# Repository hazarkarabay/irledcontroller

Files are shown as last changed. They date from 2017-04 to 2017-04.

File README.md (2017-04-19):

# irledcontroller
Simple LED Strip controller with IR remote control.

This project controls brightness of single LED strip from an IR remote. Currently it is using RC6 protocol because I have a MCE remote nearby. Thanks to [IRLib2](https://github.com/cyborg5/IRLib2), it can be configured to work with nearly any IR remote. 

Hardware
--------

A single-sided, toner transfer friendly PCB created for this project. Schematic and board files included in Hardware folder. You'll need [EAGLE](http://www.autodesk.com/products/eagle/free-download) for opening them.  
ATMega328 receives and decodes IR signals, reads an LDR to decide its status while first power-on and PWMs a N-Channel MOSFET to control lights. You'll need supply required voltage for your LED strip to this board. LED strips are generally 12V and board will work with 9-25V LED strips. 30V is absolute maximum for on-board regulator. On-board power MOSFET AO3406 can support up to 3.5A load, please check your strips' power requirement.  
Board also can support Arduino environment (supports DTS reset).

Software
--------

Software written in Arduino environment and commented heavily. Currently it uses 3 IR remote buttons to toggle light and increase/decrease brightness. It uses psychometric lightness formula (CIE 1931) for adjusting brightness and can fade in/out very smoothly (to human eye).  
Currently it uses Timer1 at 12bit mode for PWM. ATmega328 can switch at ~4kHz on this mode. Faster PWM frequencies needs reduced duty cycle resolution. 

Things to know
--------------

Since switching frequency of 4kHz is in audible range, this can leads audible noise. I did not hear anything in my application but you must aware of that.  
The board has an LDR and it only used in first power up. If the ambient light is low while powering on, it will fade lights to %100. After first start-up LDR status is ignored currently (no auto lights-on at night, sorry).  
ATMega328 is way overkill for this kind of project but I don't have any ATTinys in my hand. Because I have relatively high computing power at my hand, I didn't used lookup tables for CIE 1931 calculation, which deals with floats and exponentials. You probably want use a lookup table if you need to use ATTiny.  
If you want use serial debug output, uncomment `#define DEBUG` at line 21.
  


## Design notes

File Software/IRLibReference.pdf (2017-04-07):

User's Manual for IRLib2.

# A Library for Receiving, Decoding and Sending

Infrared Signals Using Arduino.

(September 2016)
This library is designed for using Arduino controllers for receiving, decoding and sending infrared signals such as those used by infrared remotes on consumer electronics. The work is based on an earlier library called IRremote which was created by Ken Shirriff. IRLib version 1.x was a major rewrite of that system. IRLib2 is a significant rewrite from IRLib 1.x. IRLib2 it is not fully backwards compatible with IRLib1 however it should take minimal effort to update any programs to use the new library. This is especially true if you are only using the interface of the library and not relying on any internals. See Appendix A for a discussion of the differences between IRLib2 and IRLib1 and an explanation of the reason for the choices I made in the rewrite. In this document any mention of IRLib should be construed to mean the current IRLib2 unless otherwise specifically specified. Also throughout the document we will make note of a few of the specific differences between IRLib2 and IRLib1.
One of the main differences we will note here is that IRLib1 was a single library with a single header file that included everything. You would make use of it by inserting the line… #include <IRLib.h>
However IRLib2 is more modular in design. It is actually organized into 6 different folders and many multiples of header files. To make the most efficient use of the libraries you should include only those header files which you actually need. However to assist in quickly converting older sketches to the new system, you can do…
#include <IRLibAll.h>

This will include the entire package into your sketch including all receivers and all protocols. While the linking loader will eliminate some portions of the library that you do not actually use, it will not eliminate everything that is unused. Additionally there is another file… #include <IRLib2.h>
This will include only the original seven protocols supported by IRLib1. The use of these all-inclusive include files is not recommended if you are concerned about the size of your code. We will use it occasionally in sample sketches just to simplify things. We will later describe the procedure for including only the specific pieces of the code that you actually need to use.
This manual is divided into three major sections. First is a complete reference of all the classes, structures and methods included in the library. The reference section is designed for those who want to make maximum use of the facilities of the library. However you may not need to understand everything in this section in order to use it. We suggest that novices proceed to part two which is the tutorials section. There you will find some examples of the basic use of the library. Finally you can move on to the third section of this documentation which explains how to add additional protocols to the decoding and sending sections.
There are also three appendices to this document. Appendix A as mentioned we explains the differences between IRLib2 and IRLib1 and gives an explanation of why we made the changes. Appendix B describes a special notation called IRP notation that is used in some online documentation to describe a particular IR protocol. Appendix C provide some guidance about our coding standards so that if you contribute to the library you can help maintain the same look and feel.
Note also that the code is well commented and skilled programmers who are familiar with infrared protocols and Arduino hardware or anyone interested should simply browse through the code itself for useful information.
This document is current for the original release of IRLib2 and may not be fully updated if there are minor bug fix releases. Always see CHANGELOG.txt for the latest information. The entire package of code, sample programs, and this documentation is copyright ©2016 by Chris Young and released under the GNU GENERAL PUBLIC LICENSE Version 3. See LICENSE.txt for a copy of the license. Also see COPYRIGHT.txt for more information including acknowledgment of major contributors to this package.

## 1. IRLib Reference

This section is intended to be a complete reference to the classes, methods, and structures used in the library. It is divided into the following sections:
1.1 Receiver Classes
1.2 Decoder Classes
1.3 Sending Classes
1.4 Protocol Details
1.5 Hardware Considerations

1.1 Receiver Classes
IR data is received on an input pin of the Arduino as a square wave of pulses of varying lengths. The length of the on and off pulses encodes the data. It is the job of the receiver class to record the timing of the pulses and the spaces between them. The data is stored in an array and passed to the decoder class. This section contains an overview discussion of the receiving process, with an explanation of the base receiver class and three derived classes each with its own unique characteristics. In addition to the receiver classes which records basic pulse widths, there is an additional receiver class for measuring the modulation frequency of an IR signal. 1.1.1 Receiver Overview
Infrared signals are received by an IR receiver device such as the TSOP4438 or TSOP58438 or similar. See the section 1.5 Hardware Considerations for details. Although IR signals are sent as a series of modulated pulses, these receivers filter out the modulations and send you a signal in the form of a clean square wave. If you want to measure the frequency of a modulated signal, you will need a device such as a TSMP58000 which does not filter the signal.

The output of the receiver is connected to one of the digital input pins of your Arduino. It is the job of the receiver class to monitor this signal and to determine the length of the pulses known as “marks” and the length of the intervening idle periods known as “spaces”. The hardware receiver devices typically are normally high signal and then go low when a signal is received. However the code compensates for this so it is useful to think of a “mark” as being “on” and a “space” as being “off”.

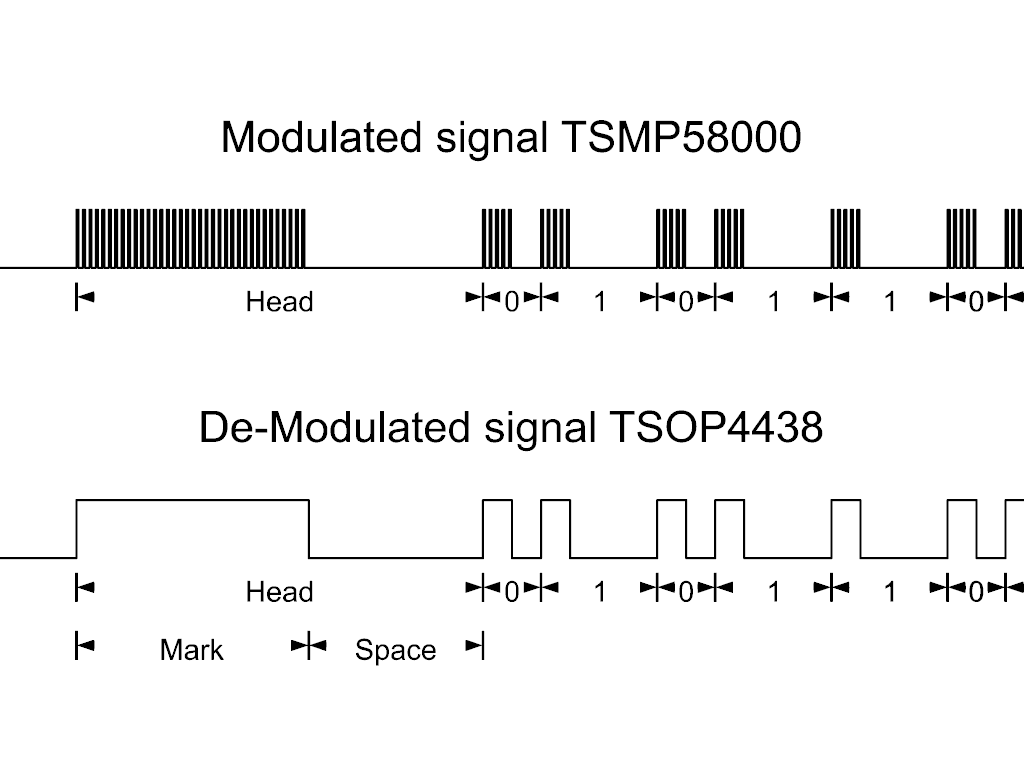
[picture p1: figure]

The duration of marks and spaces is measured in microseconds (1/1,000,000 of a second). Microseconds are often abbreviated as "µs". Note however that the software makes use of the built-in Arduino function “micros(void)” which returns results in four microsecond granularity. This means that values are always a multiple of four. This is for typical 16 MHz clocks on most Arduino models. On 8 MHz models results are in eight microsecond granularity. So whatever results we achieve are going to be no more accurate than that.
The receiver software is organized as a base class which of itself is not functional but contains methods which are common to all of the classes and three derived classes. Additionally there is a frequency measuring class is a library of its own. The classes are:
- IRrecvBase Abstract base class
- IRrecv | Original receiver class which uses 50 µs interrupt sampling
- IRrecvPCI | Uses pin change interrupts to measure pulse duration
- IRrecvLoop Uses a tight code loop to poll the input pin

- IRLibFreq Measures the modulation frequency using TSMP58000
The code for the base class and the IRrecvLoop can be found in the IRLib2 folder and the code for the other two derived receiver classes and frequency class each have their own folder. To use one of the receivers, you will have to include its header file in your sketch. You do not need to include the base class header file. You pass the pin number to which you receiver device is connected in the constructor of the object. For example to use the IRrecv receiver you would do the following…
#include <IRLibRecv.h>

IRrecv myReceiver(2);//create instance of receiver using pin 2
Similarly for the PCI version you would do…
#include <IRLibRecvPCI.h>

IRrecvPCI myReceiver(2);//create instance of receiver using pin 2 And finally the "loop" version would be…
#include <IRLibRecvLoop.h>

IRrecvLoop myReceiver(2);//create instance of receiver using pin 2
You can name the receiver object anything you want but to simplify our explanations we will presume that you have created a receiver object named "myReceiver". Although the library implements three different extensions to the base receiver class, you should have one and only one instance of a receiver class in your program. This is because all of the classes share one set of global data and methods in common. The data must be declared globally in the library because it is accessed by interrupt service routines (called ISR routines). The structure of an interrupt service routine does not allow for the passing of any parameters. Therefore any data that the ISR accesses must be global. It is possible to create both a receiver object and the frequency detection object but you should have no more than one of each.
The data is stored in an array of uint16_t values. The first element of the array is the number of microseconds from the time the receiver is enabled until the time the first mark is received. This gap is typically discarded by the decoding routines. From there on, odd-numbered elements of the array contain the duration of the marks and even-numbered elements contain the duration of the spaces.
Most of the receiver classes are interrupt driven. This means that once they are initialized, you can go off and do whatever you want until a complete sequence has been received. You determine when the sequence is complete by polling the method getResults() and when it returns true you can then obtain the results. Once a complete sequence has been received, the receiver class ignores any subsequent signals until it is reinitialized by you. However the IRrecvLoop is not interrupt driven. It does nothing until you call getResults(). It then sits in a tight loop and does not release control back to you until the complete signal has been received.
You should read the next section about the base class because most of the methods work identically regardless of which derived class you actually instantiate. You should then read the section on the class which you are going to use so that you will understand the class specific issues.

Here is an extremely simple sample sketch showing the use of the IRrecv class. Either of the other two classes could be substituted in this example. You may wish to refer to this sample code while reading the description of the methods.
#include <IRLibRecv.h>

IRrecv MyReceiver(2); //Create the receiver. Use pin 2

#include <IRLibDecodeBase.h>

#include <IRLib_P01_NEC.h>

#include <IRLibCombo.h>

IRdecode MyDecoder;

void setup() {
Serial.begin(9600);
MyReceiver.enableIRIn();//start receiving
}

void loop() {
if (MyReceiver.getResults()) {//wait till it returns true MyDecoder.decode();
MyDecoder.dumpResultso();
MyReceiver.enableIRIn(); //restart the receiver
}
}
1.1.2. The IRrecvBase class
This base class is an abstract class which in and of itself is not functional but contains common code for the other receiver classes. The code is implemented in IRLib2/IRLibRecvBase.cpp, and the prototype in IRLib2/IRLibRecvBase.h is…
class IRrecvBase {
public:
IRrecvBase(void) {};
IRrecvBase(uint8_t recvPin);
bool getResults()(const uint16_t timePerTicks=1); virtual void enableIRIn(void);
virtual void disableIRIn(void);
void enableAutoResume(uint16_t *P);
void setFrameTimeout(uint16_t frameTimeout); void blink13(bool enableBlinkLED);
uint16_t markExcess;
protected:
void init(void);
};

### 1.1.2.1 Constructor IRrecvBase

The prototype for the constructor is… IRrecvBase(uint8_t recvPin);

The value passed is the pin number to which the receiver is connected. Note: previous versions of the constructor for IRrecvPCI were passed the interrupt number instead of the pin number but now all receiver classes consistently have the pin number as its only parameter. Creating an instance of the receiver class does not enable the receiving of data. You must enable the receiver by calling enableIRIn().

### 1.1.2.2 Method enableIRIn

The receiver does not begin recording data until you call this method. Its prototype is… void enableIRIn(void);
This method sets the input pin to input mode and resets the index into the array of data values to zero. On the interrupt driven classes this enables interrupts and the receiver starts recording intervals. However when using the IRrecvLoop class, recording of signals does not begin until you call getResults().
Once the receiver is running you then need to poll the class to see if a complete sequence has been received. You do this by repeatedly calling getResults().
After you have finished processing the received data, you need to call enableIRIn() again to tell the receiver that you want more data. Even if you have enabled the auto-resume feature, you still need to call this method when you are ready for more data so that the receiver knows that it is safe to reuse the buffer. We considered renaming this method to "needMoreData" but in the long run its current name is more accurate. A complete discussion of the auto resume feature can be found in the section 1.1.2.4 Method useAutoResume below. NOTE: In IRLib1 there were 2 methods for starting the receiver. The method "myReceiver.enableIRIn()" was used to initialize the receiver and the method "myReceiver.resume()" was used to restart the receiver after you had finished processing the data. However if you also use the sending class it would disable input because it uses the hardware timers for different purposes. Therefore you would have to use "enableIRIn()" to restart after sending. It got too confusing to remember whether you needed to use "resume()" or "enableIRIn()" so we just eliminated the "resume()" completely. That method no longer exists in IRLib2. Now you just use "enableIRIn()" whether you are initializing for the first time or restarting. See Appendix A for more details.

### 1.1.2.3 Method getResults

After you have initialized receiving with enableIRIn you need to repeatedly call getResults() to see if a complete sequence has been received. The prototype for this method is…
bool getResults(const uint16_t timePerTicks=1);
This method will return “true” when a complete sequence has been received and will return “false” otherwise. The optional parameter is a multiplier which converts the recorded data into microseconds. The IRrecv class produces results in 50 µs ticks. It passes the number 50 as the parameter so that getResults() will multiply the values in the array by 50 to convert them into actual microseconds. The other two receiver classes use the default multiplier 1 because they record actual microseconds and do not need converting. This parameter is only used by the base class and is not necessary or present in any of the actual derived classes you will use. When a complete sequence has been received by the class it does not continue recording signals. It also does not normally resume recording once you have called getResults() because your decoder may be using the same array as the receiver and you do not want the receiver overwriting the array before you get it decoded.
To resume receiving data you must again call "enableIRIn()".

### 1.1.2.4 Method enableAutoResume

All three receiver classes capture their data in a globally declared buffer we will describe as the "receiver buffer". The decoders access that data through a pointer which points to what we will describe as the "decoder buffer". Normally the decoder buffer pointer points to the receiver buffer so they essentially same buffer.
If the receiver would continue recording the next frame of data before you had finished processing the first one, it would get overwritten. In some instances however you want it to resume receiving as quickly as possible so you do not miss the next frame while you are processing the first one. You can however declare an external buffer for the decoder to use and tell the receiver that it should automatically copy the data from the receiver buffer to your external decoder buffer and automatically resume. This is especially useful to use this external buffer and auto resume whenever you are using the IRrecvPCI receiver. That receiver has difficulty determining that the first frame has completed unless a secondary frame has begun. We highly recommend the use of this auto resume feature whenever you are using the IRrecvPCI receiver. Of course this feature requires 200 bytes of RAM memory which is very scarce on most Arduino platforms so you may not be able to use this feature if you cannot afford to declare the extra buffer space.
Note that this method is not available when using the IRrecvLoop receiver class because that class is not interrupt driven. Therefore you cannot multitask by receiving signals while you are decoding a previous sequence.
The prototype for this method is…
void enableAutoResume useExtnBuf(uint16_t *P);
Below is an excerpt of the autoResume sample sketch that shows how to use this method. You declare the buffer and then invoke the method in your setup function prior to starting the receiver with enableIRIn(). When a sequence is complete and getResults() returns true, the data will be copied to "myBuffer" and it will automatically start recording the next available sequence even though you have not yet invoked enableIRIn().
Whether using auto resume or not, in your main loop do not re-invoke enableIRIn() until after you have processed all of the data. If by chance you have not finished processing the first frame when the second one is completed, the receiver will not auto resume again until you have invoked enableIRIn(). Essentially invoking that method tells it that it is safe to write into the decoder buffer.
uint16_t myBuffer[RECV_BUF_LENGTH];

void setup() {
//Enable auto resume and pass it the address of your extra buffer myReceiver.enableAutoResume(myBuffer);
myReceiver.enableIRIn(); // Start the receiver
//… Other initialization code here…
}
void loop() {
//Continue looping until you get a complete signal received if (myReceiver.getResults()) {
myDecoder.decode(); | //Decode it
myDecoder.dumpResults(true); //Now print results myReceiver.enableIRIn(); //Tell receiver we are ready
}
}
You should only invoke enableAutoResume one time in your setup function and it must be before enableIRIn().
NOTE: In IRLib1 there was a decoder method "useExtnBuf(void *P)" that
would allow you to manually resume receiving before you were done
processing the data. It did not however solve the problem with IRrecvPCI possibly missing the secondary frame. When we first implemented auto resume, we implemented was an option in the useExtnBuf method however was extremely confusing when you should call enableIRIn. If you are using external buffer but using auto resume then you would reenable before decoding. But if you are using auto resume you would reenable after decoding. We eventually concluded that auto resume was so useful that there was no reason to use an external buffer without it. It also made more logical sense to make this a method of the receiver class than the decoder class. It isn't so much about adding an external buffer to the
decoder but it is more about changing the behavior of the receiver. See
Appendix A for more details.
Many thanks and acknowledgment to contributor Gabriel Staples who contributed auto resume code that was inspiration for our implementation.

### 1.1.2.5 Method setFrameTimeout

The receiver measures the length of marks and spaces and when it finds an especially long-duration space it assumes that is the end of the frame of data. This time period is called the "frame timeout" value. Any space which is found to exceed that value is presumed to be the end of frame and a new frame begins with the next mark. The default value is specified in IRLib2/IRLibRecvBase.h as follows…
#define DEFAULT_FRAME_TIMEOUT 7800

If you wish to change the value for a particular application sketch you can do so with the following method…
void setFrameTimeout(uint16_t frameTimeout);
We chose the default value to be 1.25 times the largest space any valid IR protocol might have. Our research shows that in Ken Sherriff's IRremote library ir_Dish.cpp they use

DISH_RPT_SPACE 6200 while another reference says about 6000. If we take 6200*1.25= 7750 rounded up we will use 7800. Previously IRLib1.x the default value was 10000 which was probably too large. Thanks to Gabriel Staples for this note. We had to implement this is a method because the IRrecv class needs to convert this value into a number of ticks.

### 1.1.2.6 Method blink13

For debugging purposes you may want to know if your Arduino is receiving a signal. If you call this method then pin 13 will be blinked on every time a mark is received and blinked off with a spaces received. The default is off. The prototype is…
void blink13(bool enableBlinkLED);

### 1.1.2.7 Method disableIRIn

Even when not receiving data or waiting to receive data, the ISR may remain active but remains in a do-nothing state. If you want to truly shut down the ISR you can call this method. The derived method should disable the ISR and then call this base method to then turn everything off. The prototype is…
void disableIRIn(void);

### 1.1.2.8 Variable markExcess

There is one value in the class that you can change directly. It is…
uint8_t markExcess;
Depending on the type of IR receiver hardware you are using, the length of a mark pulse is over reported and the length of a space is underreported. Based on tests performed by Ken Shirriff who wrote the original IRremote library upon which this library is based, the length of a received mark is about 100µs too long and a space is 100µs too short. IRLib1.x used that value however my own experience is that 50µs is a better value so that is the default for IRLib2. You can change that value based on your own experiences by changing the value for example… myReceiver.markExcess= 75;
You can examine or change this variable as desired. It is applied by adding that value to all odd-numbered elements of the time interval buffer and is subtracted from even-numbered elements when the data is passed to your decoder by getResults().

### 1.1.2.9 Protected Method init()

There is one protected method of the base class which is used for internal use.
void init(void);
Because it is protected you cannot call it in your sketch and you would have no need to do so.
1.1.3. IRrecv Class
This receiver class is based on the original receiver created by Ken Shirriff in his library IRremote upon which this library is based. It uses a hardware timer to trigger an interrupt every 50µs. Inside the interrupt routine it counts the number of these 50µs ticks while the pin is a mark and when the state changes it counts how many ticks in the space. When it receives an extraordinarily long space it presumes that the sequence has ended. It sets an internal flag noting that the sequence has been received. It stops recording time intervals and when the user calls getResults() the next time it will return true.
The internal hardware timer used is controlled by settings in the file IRLibProtocols/IRLibHardware.h. Each type of Arduino platform such as Arduino Uno, Leonardo, Mega etc. has a choice of different timers. For example the Uno defaults to TIMER2 while the Leonardo defaults to TIMER1 because it does not have a TIMER1. You may need to change the default timer in the event of a conflict with some other library. For example the Servo library makes use of TIMER1 so if you’re using a Leonardo with a servo you would need to change the value in IRLibHardware.h to use a different timer.
The prototype of the class is in IRLibRecv/IRLibRecv.h and the code is implemented in IRLibRecv/IRLibRecv.cpp. This makes this class essentially a library of its own. If it had been included in the IRLib2 folder, it's globally declared ISR might conflict with other libraries even if you did not create an instance of this class. The prototype is…
class IRrecv: public IRrecvBase {
public:
IRrecv(uint8_t recvPin):IRrecvBase(recvPin){}; void enableIRIn(void);
bool getResults(void);
void disableIRIn(void);
void setFrameTimeout(uint16_t frameTimeout);
};
Of course this class also inherits other methods from the base class that are not listed in this prototype. As previously noted in the discussion of the base class, the constructor is passed the pin number of the input pin to which you have connected your receiver. There are no restrictions and any digital input pin can be used.
You will need to enable input by calling enableIRIn() and will need to poll the getResults() method in your loop until it turns true. Although in our example code we called getResults() in a very small loop, because this class is interrupt driven you can do just about anything else inside your main loop function and only call getResults() when you are ready.
A reminder that when a complete stream has been received, no additional measurements are taken until you call the enableIRIn() method again. Do not call enableIRIn() until you are finished with the data from the previous frame even if you have enabled auto resume.
Because this receiver only samples the input every 50µs there is a chance that it could sample at inopportune times and be as much as 98µs off when measuring intervals. If you are decoding a known protocol, this margin of error is usually acceptable. The decoder functions typically use +/-25% tolerance and that produces acceptable results. However if you are trying to analyze an unknown protocol you would be better suited to use either the IRrecvPCI or IRrecvLoop receiver class instead.

1.1.4. IRrecvPCI Class
This receiver class makes use of the hardware interrupt available on some pins of Arduino microcontrollers. It was created because it gives more accurate timings than the original IRrecv class which only samples the input every 50µs. The code as well as the IRfrequency code described in the next section is loosely based upon and inspired by work by the developers of the AnalysIR program. AnalysIR is a Windows-based application which allows you to graphically analyze IR input signals through an Arduino, Raspberry Pi or other microcontrollers systems. Many thanks to the developers of that software for their assistance and input into the development of this class. You can find more about their software at http://analysir.com
The class sets up the pin change hardware interrupt which calls the interrupt service routine every time the input pin switches from low to high or high to low. At each change, the code calls the built in function micros() and that value is subtracted from the timestamp of the previous change. Because the micros() function is only accurate to 4µs on 16 MHz systems or 8µs on 8 MHz systems, that is the limitation of accuracy of this method.
While it is much more accurate than the original IRrecv class which only had 50µs or worse accuracy, it may not be suitable for everyday use. The class has difficulty determining when a sequence has ended. Normally we assume a sequence has ended when a space interval is longer than a certain amount. But we cannot know how long the final trailing space is until the first mark of the next sequence begins. The code attempts to compensate for this by checking for an extremely long space each time that the user calls getResults(). However unless you call that routine extremely frequently, it is more likely that the next sequence will begin. While that does not adversely affect the reception and subsequent decoding of an initial sequence, if the next sequence comes quickly then the receiver may miss it or may start reception in the middle of a sequence thus giving only partial and therefore jumbled results. This problem can be alleviated by using the auto resume feature however that requires an external buffer which can use up a considerable amount of valuable RAM memory. Auto resume will ensure that 2 frames that arrive close together will be properly received and decoded so it is highly recommended when using this type of receiver.
As with the IRrecv class, the interrupt service routine is put into an idle state once a completed sequence has been detected and is not re-enabled until you call enableIRIn().
The prototype of the class is in IRLibRecvPCI/IRLibRecvPCI.h and the code is implemented in IRLibRecvPCI/IRLibRecvPCI.cpp. This makes this class essentially a library of its own. If it had been included in the IRLib2 folder, it's globally declared ISR might conflict with other libraries even if you did not create an instance of this class. The prototype is…
class IRrecvPCI: public IRrecvBase {
public:
IRrecvPCI(uint8_t pin);
void enableIRIn(void);
bool getResults(void);
void disableIRIn(void);
private:
uint8_t intrNum;
};

Of course this class also inherits other methods from the base class that are not listed in this prototype. As previously noted in the discussion of the base class, the constructor is passed the pin number of the input pin to which you have connected your receiver.
NOTE: In IRLib1 the constructor for this class was passed the interrupt
number and not the pin number. This behavior has changed to be pin number. It then converts that pin number into the interrupt number using the built-in Arduino function "digitalPinToInterrupt(pin)" as is
recommended at https://www.arduino.cc/en/Reference/AttachInterrupt
See that page for more details.
Only certain particular pins support the pin change interrupt depending on which type of Arduino you are using. You can verify that the pin is supported by putting the following code in your setup function.
#define MY_PIN 2 //pin number 2 if(digitalPinToInterrupt(MY_PIN)==NOT_AN_INTERRUPT) { Serial.println(F("Invalid frequency pin number."));

while (1) {};//infinite loop because of fatal error
}
The table below is a partial list of the pin numbers that are available on various platforms. The table was adapted from http://arduino.cc/en/Reference/AttachInterrupt and you should reference that page for more information about the Arduino built in function attachInterrupt() that is used by this class.
Board | Digital Pins Usable For Interrupts
Uno, Nano, Mini, other 328-based | 2, 3
Mega, Mega2560, MegaADK | 2, 3, 18, 19, 20, 21
Micro, Leonardo, other 32u4-based | 0, 1, 2, 3, 7
Pinoccio | 4, 5, SCL(15), SDA(16), RX1(13), TX1(14), 7
Zero* | all digital pins, except 4
MKR1000 Rev.1* | 0, 1, 4, 5, 6, 7, 8, 9, A1, A2
Due* | all digital pins
101* | all digital pins
*These platforms have not been tested with IRLib but should theoretically work with this receiver. They are not however supported for sending IR signals or using the IRrecv receiver class.
You will need to enable input by calling enableIRIn() and will need to poll the getResults() method in your loop until it turns true. Although this receiver is interrupt driven and you should be able to do just about anything inside your main loop, we recommend that you call getResults() as frequently as possible because this receiver has difficulty detecting when a frame is complete. If however you are using the auto resume feature, this restriction is not necessary. You can take considerable time doing other things in your main loop when using auto resume. We recommend that if you can afford to allocate an external buffer and use auto resume that you should do so with this receiver for best results.
A reminder that when a complete stream has been received, no additional measurements are taken until you call the enableIRIn() method again. Do not call enableIRIn()

until you are finished with the data from the previous frame even if you have enabled auto resume.
1.1.5. IRrecvLoop Class
This version of the receiver class uses a tight internal loop to poll the input pin. It makes no use of hardware interrupts or internal timers to compute the intervals. It does use the “micros()” function to compute time intervals so it has the limitations of that function. Specifically the function is only accurate to 4µs on 16 MHz systems or 8µs on 8 MHz systems. Although we have attempted to code the loop as tightly as possible there still is some amount of overhead in the loop itself which could affect the accuracy. However it is still much more accurate than the 50µs off the original IRrecv. This makes it a good choice for analyzing unknown protocols. Because no interrupts are involved, the class does not begin recording intervals when you initially call enableIRIn() as is the case with other classes. This class only samples input when you call getResults(). That method then takes over control of your program and does not relinquish it until it has received a complete sequence. The function always returns true. Because it takes over control of your program and does not allow you to do other things while it is looking for a sequence, this version of the class may not be practical for everyday use. This class cannot make use of the auto resume feature because it is not interrupt driven and therefore cannot multitask.
You will still need to call enableIRIn() when you have finished processing your data to get the receiver ready to receive again. However the actual data collection will not begin again until you call getResults().
The prototype of the class is in IRLib2/IRLibRecvLoop.h and the code is implemented in IRLib2/IRLibRecvLoop.cpp. Unlike the IRLibRecv and IRLibRecvPCI, this receiver should never conflict with any other libraries. For that reason it does not need to be a library unto itself. The linking loader will eliminate it completely if you do not create an instance. Therefore the code files are located in the IRLib2 folder. The prototype is…
class IRrecvLoop: public IRrecvBase {
public:
IRrecvLoop(uint8_t recvPin):IRrecvBase(recvPin){};
bool getResults(void);
};
Although the prototype only lists the constructor and getResults(), all of the methods of the base class are technically available. However as we mentioned earlier, auto resume is not available so enableAutoResume() does nothing. Similarly because it is not interrupt driven the method disableIRIn() does nothing. Like the other receivers, the value passed to the constructor is the number of the receiver pin. Any available digital input pin can be used.
Because this class uses no hardware timers and no hardware interrupts it is completely hardware independent and should work on any Arduino-like platform even those which are not technically supported by this library.
1.1.6. Global Receiver Structures and Functions
There are 3 additional global functions in IRLib2/IRLibRecvBase.h and implemented in IRLib2/IRLibRecvBase.cpp. These functions are not methods of any class. Two of these are global because they are referenced internally by the ISR and you cannot pass variables or objects to an ISR. The third of these global functions is somewhat related to both sending and receiving but doesn't really belong in either class. In this section we will also describe a structure containing other global variables that were again made global so that they can be referenced inside the ISR.

### 1.1.6.1 Function IRLib_noOutput

Some users create custom boards for input and output of IR signals and those boards are connected to their Arduino even in the case when the sketch only does input. It is theoretically possible that when running an “input only” sketch that the output pin could initialize high and your output LED would be on all the time. LED driver circuits are sometimes designed to overdrive the LED because it is used only intermittently. If it were to be accidentally left on continuously, it could burn out your circuit. If you want to ensure that this does not happen you can call this function. We are unsure if this function is actually necessary but we provide it out of an abundance of caution. The prototype is…
void IRLib_noOutput(void);
NOTE: This previously was a method of the base receiver class but it really doesn't have anything to do with receiving so we renamed it and made it a standalone function.

### 1.1.6.2 Function IRLib_doBlink

This function is for internal use only. It is called by the ISR or in the case of the loop receiver by IRLibRecvLoop::getResults(). It does actual blinking of the pin 13 indicator LED. The prototype is…
void IRLib_doBlink(void);

### 1.1.6.3 IRLib_IRrecvComplete

This function is for internal use only. It is called by the ISR and implements much of the logic of the auto resume feature. It is not used by IRLibRecvLoop::getResults() because that receiver does not support auto resume. The prototype is…
void IRLib_IRrecvComplete(uint8_t Reason);
This function is called by both the 50us and PCI ISR in one of two circumstances:
1) The SPACE was long enough that we are sure the frame is over and ready to process.
2) The buffer overflowed we have to quit.
The parameter is for debugging purposes only.

### 1.1.6.4 Global data recvGlobal

In addition to the base class and the three derived classes that are used for receiving IR signals, there is a globally defined structure that is used by the classes. Good object-oriented design would have us put all of the data associated with a class inside the class itself. However much of the data we use needs to be accessible from an interrupt service routine. A limitation of an ISR is that we cannot pass it any parameters and it cannot be part of a class. So all of the data used by the ISR must be in some globally available location. Unless you’re going to implement your own receiver class or you create custom decoder classes need access to this data, you need not deal with the structure. It is primarily for internal use. The type "recvGlobal_t" defined in IRLib2/IRLibGlobal.h as shown below. A single global instance of the structure is declared in IRLib2/IRLibRecvBase.cpp as follows
recvGlobal_t recvGlobal;
Additionally the ISR routines keep track of what they're doing by implementing a state machine. The state machine is only used by the IRrecv and IRrecvPCI classes. The current state of the state machine is stored in a field of the global structure of type "currentState_t". Below is the definition of the states of the state machine, and the 2 structure types that are used by the receivers. The actual code in IRLib/IRLibglobal.h Is more extensively commented than what is shown here. We will briefly describe each field below.
// Receiver states. This previously was enum but changed
// it to uint8_t to guarantee it was a single atomic 8-bit value. #define STATE_UNKNOWN 0
#define STATE_READY_TO_BEGIN 1

#define STATE_TIMING_MARK 2

#define STATE_TIMING_SPACE 3 #define STATE_FINISHED 4

#define STATE_RUNNING 5

typedef uint8_t currentState_t;

typedef struct {
uint8_t recvPin; | // pin number for receiver
bool enableAutoResume; // flag tells if we should auto resume uint16_t frameTimeout; // set by "setFrameTimeout()" uint16_t frameTimeoutTicks;// = frameTimeout/USEC_PER_TICKS

bool enableBlinkLED;

volatile bool decoderWantsData; //previous decode is finished. volatile bool newDataAvailable; //tells getResults
volatile bool didAutoResume; //tells getResults

volatile uint16_t recvBuffer[RECV_BUF_LENGTH];
volatile bufIndex_t recvLength;

volatile uint16_t* decodeBuffer;
volatile bufIndex_t decodeLength;
volatile uint32_t timer; | // state timer, counts 50uS ticks
volatile currentState_t currentState; | // state machine
}
recvGlobal_t;
extern recvGlobal_t recvGlobal; //declared in IRLibRecvBase.cpp
The first four fields of the recvGlobal structure are initialized by the receiver class and once initialize will probably not change. The first three are pretty much self-explanatory. The field uint16_t frameTimeoutTicks is only used by the 50 µs IR recv class it is always equal to frameTimeout/USEC_PER_TICKS (which is almost always 50).
The next field enableBlinkLED tells whether or not to blink indicator LED.
The remaining fields are declared volatile because they may be accessed both inside and outside the ISR. The next three fields are flags that help facilitate auto resume. The flag decoderWantsData is the way the decoder tells the ISR that it is safe to write new data into the decode buffer. The flag newDataAvailable is the way the ISR tells getResults() that a complete sequence has been received. The flag didAutoResume is set by the ISR and tells IRLibRecvBase::getResults() that because we did auto resume, the ISR has already copied the data from recvGlobal.recvBuffer to recvGlobal.decodeBuffer. However getResults() still needs to perform some math on the data to convert from ticks to microseconds if necessary and to make the "markExcess" adjustments.
The field recvBuffer[RECV_BUF_LENGTH] is the actual receive buffer. The receivers always initially accumulate the timing of the marks and spaces in this buffer. The field recvLength tells the number of entries in that buffer.
The field decodeBuffer is a pointer that the decoders use to access the timing data. If there is no external buffer for auto resume then this pointer will point to recvGlobal.recvBuffer and essentially the decode buffer is the receiving buffer. However if an external buffer and auto resume have been enabled, then this pointer points to that external buffer. In that case the external buffer is the decode buffer. The field decodeLength is the number of entries in the decode buffer.
The field uint32_t timer is a temporary variable used to count the number of ticks or microseconds of the current interval.
The field currentState_t currentState is the current state of the state machine. Its legal values are defined above.
Near the top of IRLib2/IRLibGlobal.h are the following definitions…
#define RECV_BUF_LENGTH 100

#if (RECV_BUF_LENGTH > 255)

typedef uint16_t bufIndex_t;
#else

typedef uint8_t bufIndex_t;
#endif

The #define is the length of the receiver and decoder buffers. The default value of 100 will work for most electronic protocols. However some protocols used by air conditioners and fans have extremely lengthy frame sizes. Because each entry in the buffer is uint16_t it will use two bytes of RAM. You'll want to use as small value as possible. If you need more than 255 entries, the conditional compile directives will make sure that your index into the buffers is sufficient to handle that many entries.
1.1.7 IRfrequency Class
Normally you would use a TSOPxxxx IR receiver device to detect IR signals. These devices demodulate the signal into square waves measured in hundreds or thousands of microseconds. However the actual IR signals are modulated at frequencies from 36 kHz as high as 57 kHz depending on the protocol. If you have an unknown protocol, you can typically receive such a signal using a device that has been tuned to 38 kHz however if you then want to accurately retransmit the signal you need to know the actual frequency. This requires a different type of receiver such as a TSMP58000 that passes the modulated signal through directly. See the section Hardware Considerations for more info on connecting these devices.
Because the signals are so short (17.5 µs to 27.7 µs) it is difficult to accurately measure them. The only way is to use a hardware interrupt pin and an extremely fast interrupt service routine. However these measurements are limited to the accuracy of the micros() function which is only accurate to 4 µs on 16 MHz systems and 8 µs µs on 8 MHz systems. The accuracy of the measurement can be slightly improved by taking several hundred measurements and averaging them.
The IRfrequency class implements an interrupt driven system for measuring frequency. See the examples folder for sample code using this class. The IRLibFreq/dumpFreq example requires both a TSOP and TSMP device connected to 2 different pins. It detects both the frequency using IRfrequency and the pattern of pulses using IRrecvPCI or IRecvLoop receivers. You could also use the original IRrecv receiver class but it degrades the accuracy of the frequency calculation because the interrupt every 50 µs interferes. The other sample code is IRLibFreq/freq and it uses only the TSMP device to measure frequency and it does nothing else. Measuring frequency by itself is the most accurate method but there may be applications where you need to measure frequency and protocol simultaneously.
The class is not derived from the IRLibRecv class. It is a library unto itself with the code implemented in IRLibFreq/IRLibFreq.cpp. The prototype in IRLibFreq/IRLibFreq.h is…
class IRfrequency {
public:
IRfrequency(uint8_t pin);
void enableFreqDetect(void);
bool haveData(void); //detect if data is received void disableFreqDetect(void);
void computeFreq(void); //computes but does not print results
void dumpResults(bool detail); //computes and prints result double results; //results in kHz
uint8_t samples; //number of samples used in computation private:
volatile FREQUENCY_BUFFER_TYPE Time_Stamp[256];
uint8_t intrNum;
uint16_t i;
uint32_t sum;
};

### 1.1.7.1 Constructor IRfrequency(uint8_t pin)

The parameter to the constructor is the pin number to which you will connect your TSMP58000 device. Note previous versions of this library you would pass the interrupt number rather than the pin number. Only particular pins which can use the pin change interrupt can be used. See section on the IRrecvPCI class for a table showing which pin numbers are available on a particular platform. There is also sample code that shows how to see if you have chosen a valid pin number.
As with other receiver classes, you should instantiate only one copy of this class. However you can simultaneously have a frequency receiver and one of the other normal receivers at the same time.

### 1.1.7.2 Method enableFreqDetect

The class does not begin collecting frequency data until you call the enableFreqDetect() method. This attaches the interrupt routine and begins waiting for a signal. The built in interrupt service routine calls micros() each time a signal is detected. It stores the least significant 16 bits of that value in a 256 byte array. It continually detects data in the array and when it fills, the index wraps around. This overflow is very likely to occur because an IR stream will usually contain thousands of pulses. Therefore the measurement is only based upon the most recent 256 data points.
The system uses only 16 bits of timing data which is generally sufficient. If you can use more or less RAM memory, you can change the value…
#define FREQUENCY_BUFFER_TYPE uint16_t

This value can be found in IRLibFreq/IRLibFreq.h and can be changed to either uint8_t or uint32_t however 16 bit default is generally best.
If you are simultaneously receiving a signal using a TSOPxxxx device and one of the three available receiver classes as in the dumpFreq example, you can continue to operate the frequency detector until a complete sequence has been detected. However if you are measuring frequency alone as with the freq example, you need to know when to quit. You can call the haveData() method repeatedly in your main loop. It will return true if at least one buffer full of data has been collected.

### 1.1.7.3 Method disableFreqDetect

When you are finished collecting data, you should call the disableFreqDetect() method. This will detach the interrupt and no further data is collected until you call enableFreqDetect() to again. In the normal receiver classes it generally does not hurt anything to leave interrupts running however this class you really should disable it once you have collected sufficient samples. Otherwise the receiver continues collect data overwriting the data collected.

### 1.1.7.4 Methods computeFreq and dumpResults

Once you have collected the data, you then have a choice of either calling computeFreq which computes the frequency based on the timestamp data or dumpResults which will call computeFreq for you and display the results using Serial.print().
The computation measures the difference between successive timestamps. While the majority of the timestamps will be the time between pulses of the modulated signal, some of them will be the gaps caused by the spaces in the protocol. These gaps will be on the order of hundreds of microseconds rather than tens of microseconds. The computation discards these intervals and only considers those which are likely to be from the modulated signal itself. Because we’re only storing the least significant 8 to 16 bits of data, some of the values will be inaccurate. The code attempts to eliminate anything that is unusually large or unusually small. It then averages the usable samples and computes a frequency measured in kHz. The computeFreq method stores the results in a float double variable myReceiver.results. It also tells you the number of actual samples used in the computation in the myReceiver.samples. If the samples value is extremely small, you might wish to discard that data and remeasure.
1.2 Decoder Classes
IR signals are encoded as a stream of on and off pulses of varying lengths. The receiver classes only record the length of pulses which we call “marks” and the intervals between them which we call “spaces”. However it is the decoder class which identifies the protocol used and extracts the data. It provides the user with the type of protocol it found if any, the value received, and the number of bits in that value. We implement the decoder as an abstract base class and a number of additional derived classes with one class for each protocol supported. Additionally there is a class will turn your received data into a 32-bit hash code which can be used for creating a unique data value from an unknown protocol. Note however that the hash code is only good for detecting signals and cannot be used to re-create the signals for sending again. NOTE: In IRLib1 there was a universal class which incorporated seven of the supported protocols. Additional protocols were supported only through sample sketches which illustrated how to extend the base class to incorporate more protocols. If you wanted to use only one or two protocols or wanted to incorporate any protocols beyond the original seven, it required a great deal of programming on the part of the developer to use this library. The new modular design used by IRLib2 has you include the base decoding class, followed by header files for only the protocols you wish to use, followed by a file which will assemble into a decoder using all and only the protocols you want. That process is described in section
1.2.3 The Combo Decoder Class.
1.2.1. Decoding Overview
The data from the receiver class is in the form of an array of time intervals of the marks and spaces that constitute the data stream. That stream typically begins with some sort of header followed by the encoded bits of data which could be from 8 up to 32 or more bits followed by some trailer. Occasionally there are other sequences in the middle of the stream that are not actually part of the data. These signals serve to separate the data into different sections. In order to make good use of the information we need a decoder which will take this data and converts it into a single binary value which identifies the particular function the remote is using.
The data sent by a remote often contains information such as a device number, sub-device, function number, sub-function and occasionally information that designates that this is a repeated signal. The philosophy of this library is to not care about what the data represents. We take the philosophy that “You push the button and this is the stream of data that you get.” Our job is to get you that binary number usually expressed in hexadecimal and it’s up to you to decide what to do with it.
If you are using a supported protocol, that hexadecimal number can then be fed into a send class which will output the IR signal identical to the one that you received. There is one exception in that one of the decoders used for unknown protocols creates a 32-bit hash code from the input sequence. The hash code is extremely likely to be a unique representation of the original stream but there is no way to reverse that and re-create the stream from the hash code.

Different manufacturers use different protocols for encoding this data. That is what allows you to have a universal remote that can operate devices by different manufacturers and not have the signals get mixed up. That creates a problem for us because we need different programs to decode each different protocol. The library has a base decoder class each protocol has a derived class based on base class. There is also a special hash decoder class and another base class which defines common methods used by both RC5 and RC6 protocols. Below is a version of our example sketch IRLib2/examples/dump/ which you can use as a guide throughout this discussion. Note that this example uses IRLibAll.h to simplify the example but it is not recommended because it includes more code than is necessary and can make your application larger than needed. We recommend you use the combo system which we will describe in section 1.2.3 The Combo Decoder Class.
#include "IRLibAll.h"

IRrecv myReceiver(2); //create receiver and pass pin number
IRdecode myDecoder; //create decoder

void setup() {
Serial.begin(9600);
delay(2000); while (!Serial); //delay for Leonardo myReceiver.enableIRIn(); // Start the receiver Serial.println(F("Ready to receive IR signals"));
}

void loop() {
//Continue looping until you get a complete signal received if (myReceiver.getResults()) {
myDecoder.decode(); | //Decode it
myDecoder.dumpResults(false); //the results of a Now print results.
myReceiver.enableIRIn(); //Restart receiver
}
}
The IRLibAll.h among other things defines a new derived class called IRdecode which combines all of the supported protocols into a single class. You should then create an instance of that class. That file also makes available all three receiver classes so we will create a receiver as well for this example.
In the setup function it initializes the serial monitor, initializes the receiver, and prints a prompt message to the serial monitor. In the main loop we continually call myReceiver.getResults() and when it returns true we call myDecoder.decode(). That method will return "true" if it discovered one of the protocols that you are using. In this instance we want to see the results even if it did not correctly decode the data so we are ignoring the return value. We then use the myDecoder.dumpResults(true) method to print the results to the serial monitor. We then tell the receiver that we finished and we are ready for another frame of data by calling myReceiver.enableIRIn().

1.2.2. IRdecodeBase Class
The library defines a base decoding class that is an abstract class which does not in and of itself do anything. All other decoder classes are extensions of this class. The code is implemented in IRLib2/IRLibDecodeBase.cpp in the prototype in IRLib2/IRLibDecodeBase.h is as follows…
// Base class for decoding raw results
class IRdecodeBase {
public:
IRdecodeBase(void);
uint8_t protocolNum; | // NEC, SONY, RC5, UNKNOWN etc.
uint32_t value; | // Decoded value
uint16_t address; | // More data for protocols > 32 bits
uint8_t bits; | // Number of bits in decoded value
bool ignoreHeader; // Relaxed header test allows AGC to settle bool decodeGeneric(uint8_t expectedLength, uint16_t headMark, uint16_t headSpace, uint16_t markData, uint16_t spaceOne, uint16_t spaceZero); void dumpResults(bool verbose = true);//print data to serial protected:
virtual void resetDecoder(void); // Initializes the decoder bufIndex_t offset; // Index into decodeBuffer used various places
};
The constructors for the base class and for any of its derived classes take no input. Like the receiver classes you should not create multiple instances of the decoder class because they share common data structures. You instead create a universal decoder class that incorporates multiple decoders into a single class. Note: IRLib1 decoder stored all of their data internally in the object so there was not a restriction on the number of simultaneous decoder objects. This new restriction with IRLib2 should cause no problems.
Although not part of the base class, each protocol class and the combined IRdecode class have a method
bool decode(void);
This method will return true if it found one of the included protocols and false otherwise. The results can be found in 4 data fields of the class. The type of protocol detected is stored in myDecode.protocolNum. The primary data is in the 32-bit variable myDecode.value. The number of significant bits is stored in myDecode.bits. Some protocols have more than 32 bits while others need some sort of additional information such as a repeat flag or other uses. These values are returned in the 16-bit value myDecode.address.
The possible return values for protocolNum can be found in the file IRLibProtocols/IRLibProtocols.h as follows…
#define UNKNOWN 0

#define NEC 1

#define SONY 2

#define RC5 3

#define RC6 4

#define PANASONIC_OLD 5

#define JVC 6

#define NECX 7

#define SAMSUNG36 8

#define GICABLE 9

#define DIRECTV 10

#define RCMM 11

//#define ADDITIONAL_12 12 //add additional protocols here //#define ADDITIONAL_13 13
#define LAST_PROTOCOL 11 //Be sure to update this

In the sample sketch after we called the decode() method we then call dumpResults(true) to look at all of the received data. Here is an example of some typical output from dumpResults…
Decoded Sony(2): Value:58BCA Adrs:0 (20 bits)
Raw samples(42): Gap:3200
Head: m2400 s600
0:m650 s550 | 1:m1250 s600 | 2:m650 s550 | 3:m1250 s550
4:m1300 s550 5:m650 s600 | 6:m600 s600 | 7:m600 s600
8:m1250 s550 9:m650 s600 | 10:m1250 s600 | 11:m1200 s600
12:m1200 s600 13:m1200 s650 | 14:m600 s600 | 15:m600 s600
16:m1250 s600 17:m500 s700 | 18:m1250 s550 | 19:m650
Extent=32800
Mark min:500 | max:1300
Space min:550 | max:700
The output identifies this a Sony protocol which is protocol “2”. The received value in hexadecimal is 0x74BCA and is 20 bits long. The stream contained 42 intervals which is the number stored in recvGlobal.decodeLength. It then dumps out all of the values from the decode buffer which is recvGlobal.decodeBuffer[]. The first element of that array is the amount of time between initializing of the receiver and the first received mark. This gap is ignored by the decoder. The next two values are the length of the mark and space of the header sequence. The remaining values are the lengths of the marks and spaces of the data bits. Each mark is preceded by the letter “m” and spaces are “s”. The values are in microseconds. Because we used the IRrecv receiver you will note that all of the values are in 50µs increments.
At the end of the data bits, the method also reports the sum total of all of the intervals from the header through the stop bit. That information is significant for some protocols. It also tells you the maximum and minimum values of mark and space for data bits which can be useful for analyzing unknown protocols. Additional data analysis of unknown protocols can be found in the IRLib2/examples/analyze example sketch.
The sample output above is the results you get from dumpResults(true) which is the verbose version of the output. If you call dumpResults(false) you get only the top line of the output as follows…
Decoded Sony(2): Value:58BCA Adrs:0 (20 bits)
There is an additional field that you may want to set before calling your decoder…

bool ignoreHeader;
Most receiver devices include a special circuit called Automatic Gain Control or AGC that adaptively boosts the signal to a standard level so it can be properly decoded. Most protocols begin with an exceptionally long “mark” pulse which allows the AGC amplifier to have time to adjust itself. If you are getting a weak signal, this initial heading mark can come in shorter than what was actually transmitted. Consumer electronics devices such as TVs, DVD’s etc. only need to support a single protocol. So they do not need to concern themselves with the duration of the header in order to decide what to do. If the duration of their header mark is not up to protocol, they can still operate if all of the other timing values are correct. However our decoder classes all require that the received header pulse be reasonably close to the specification. You can turn off the requirement that the initial mark of the header is within normal tolerances. You do so by setting the value myDecoder.ignoreHeader=true; Setting this flag can improve the ability to decode weak signals by allowing the AGC to adjust.
Warning however if you’re using multiple protocols, it can give you inaccurate results of the protocol type. Specifically the NEC and NECx protocols are identical except for the length of the initial header mark. Therefore an NECx signal would be reported as NEC when the ignoreHeader parameter is true. Fortunately the data values are unaffected. There may be other as yet unsupported pairs of protocols which cannot be distinguished from one another except by their header.
The only remaining method in the base class is “genericDecode”. It is a general-purpose decoding routine used by many of the other protocols that share common attributes. It will be documented in the section on adding additional protocols to the library.
Earlier we mentioned that the protocol numbers were available in IRLibProtocols/IRLibProtocols.h. That header also defines a function as follows…
const __FlashStringHelper *Pnames(uint8_t Type);
You pass it a protocol number it returns a pointer to a string containing the name of the protocol such as “Sony”, “NEC” etc. These strings are stored in flash memory or program memory so that it does not use valuable data RAM memory. It is used by dumpResults() and may be useful to the end user as well.
1.2.3. The Combo Decoder Class
In IRLib1 there was an omnibus decoder class called IRdecode which combined the 7 supported protocols into a single decoder. However if you only used a small number of protocols it was wasting a lot of code space in your application. As the number of protocols we will support keeps increasing, this wasted space could be significant. We instead created a modular system in which you include the base decoder class followed by header files for only the protocols that you want to use. This can save valuable space in your program. We highly recommend that you use this system rather than including IRLib2.h or IRLibAll.h unless you really need to include absolutely everything.
First we will describe how to use the system for a single protocol. Suppose you're only receiving Sony codes. At the top of your file you would include…
#include "IRLibDecodeBase.h" //Include the base class

#include "IRLib_P02_Sony.h" | //Include the protocol you want

IRdecodeSony myDecoder; | //Create an instance of the object
Note that the name of the class we are creating is IRdecodeSony. You would of course substitute the name of some other protocol if that's what you're using such as IRdecodeNEC, IRdecodeRC5 etc. If your application also would send only Sony codes, you would include the IRLibSendBase.h prior to the protocol as well.
If you are using multiple protocols your code might look like this excerpt from our example sketch IRLib2/examples/comboDump/.
#include <IRLibDecodeBase.h> // First include the decode base #include <IRLib_P01_NEC.h> // Now include only the protocols you #include <IRLib_P02_Sony.h> // wish to actually use. The lowest #include <IRLib_P07_NECx.h> // number must be first.

#include <IRLib_P09_GICable.h>

#include <IRLib_P11_RCMM.h>

#include <IRLibCombo.h> | // After all protocols, include this

IRdecode myDecoder; | //Create an instance
We begin by including header the IRLibDecodeBase.h followed by the header files for each of the protocols you wish to use. NOTE: The lowest numbered protocol you're using must be the first included. Subsequent protocol includes need not be in numerical order but we recommend that you keep them in order anyway. If you would later decide to remove the top protocol then everything else would still be all right. When we say "lowest numbered" we do not mean that you have to use IRLib_P01_NEC.h in every sketch. We mean that among the protocols you are using, the lowest numbered one in your list must be first.
Note: If your application both sends and receives then you would also include the sending base class prior to including all of the protocol classes.
After you have included the base file and all of your protocol files you then include the file IRLibCombo.h. It defines a new derived class called IRdecode which combines all of your selected protocols into a single class. You should then create an instance of that class.
The IRdecode class inherits all of the data fields of the base class and has a single method decode() which returns true if it successfully identified the protocol. The prototype is… bool IRdecode::decode(void);
There are at least 11 protocols supported by the library. Each is implemented in his own header file which can be found in the IRLibProtocols folder. The file names are of the form IRLib_Pnn_Name.h where "nn" is the protocol number and "name" is the name of the protocol for example the Sony protocol is in IRLib_P02_Sony.h. There is no associated ".cpp" file for the protocols. All of the code is in the header file. This means that the code will be recompiled every time you compile your sketch. While this will slow down compilation slightly, the flexibility it gives us is well worth it. These files contain both the decoding and sending classes but a series of conditional compile flags insurers that if you do not include the base decode class that the individual protocol decoding classes will not compile. Similarly if you do not include the sending base class, the individual protocol sending classes will not compile. If your application both sends and receives you must include both base classes before including the protocol classes.

Complete details on the individual protocols can be found in section 1.4 Protocol Details. There are more details on how we implemented this combo system in Appendix A and in section 3 Implementing New cut protocols.
1.3 Sending Classes
The decoder classes defined by this library all return a binary data value, the number of bits in that data value, and the type of protocol received. That information can then be used to re-create the original signal and send it out using an infrared LED. The sending classes allow you to re-create the signals that are sent by remote controls using the protocols supported by this library. We implement this as an abstract base class and a derived class for each of the supported protocols. Additionally there is a sendRaw class which can be passed an array of raw timing values if you do not know the actual protocol.
NOTE: In IRLib1 there was a universal class which incorporated seven of the supported protocols. Additional protocols were supported only through sample sketches which illustrated how to extend the base class to incorporate more protocols. If you wanted to use only one or two protocols or wanted to incorporate any protocols beyond the original seven, it required a great deal of programming on the part of the developer to use this library. The new modular design used by IRLib2 has you include the base decoding class, followed by header files for only the protocols you wish to use, followed by a file which will assemble into a decoder using all only the protocols you want. That process is described in section 1.3.3
The Combo Sending Class.
1.3.1. Sending Overview
Given the information produced by the decoder classes, you can use that data to send a signal that produces the same results as the one you received. Note however that are sending classes are designed to be used with the decoder data from this library. There are a number of online references and other software such as LIRC which provide lists of binary values for different kinds of remotes and different functions. However they may have their own unique way of encoding the data that may or may not be compatible with the values used by this library. Therefore you should use the receiving and decoding classes to detect the signal from a remote and obtain the value that this library creates. Then you can use that value and the sending classes provided to re-create that stream and control some device.
Warning: if your application both sends and receives data, the sending of data uses the same hardware timer features as some of the receiving classes. This effectively shuts down your receiver class. Therefore if you are also receiving, after sending data you should always call myReceiver.enableIRIn() to restart your receiver. Although this theoretically should only affect the use of IRrecv we recommend you maintain this practice for IRrecvPCI and IRrecvLoop as well so that you have the opportunity to switch the type of receiver you are using without any unforeseen consequences.
1.3.2. IRsendBase Class
The code for the base sending class is implemented in IRLibSendBase.cpp and the prototype is in IRLibSendBase.h both of which are found in the IRLibProtocols folder. They are not in the IRLib2 folder because doing so would have automatically included global functions and structures that are not necessary for sketches that only do sending and not receiving/decoding. By making this separate we can eliminate overhead and infrastructure not necessary for send-only applications. The prototype is…
class IRsendBase {
public:
IRsendBase();
void sendGeneric(uint32_t data, uint8_t numBits,
uint16_t headMark, uint16_t headSpace, uint16_t markOne, uint16_t markZero, uint16_t spaceOne, uint16_t spaceZero, uint8_t kHz, bool stopBits, uint32_t maxExtent=0); protected:
void enableIROut(uint8_t khz);
void mark(uint16_t usec);
void space(uint16_t usec);
uint32_t extent;
uint8_t onTime,offTime,iLength;//used by bit-bang output.
};
The base class is completely abstract. The constructor takes no parameters. The methods and data fields are all for internal use or for the creation of derived classes. Unlike receiving and decoding classes, there is no restriction on creating multiple sending objects however it is more efficient to use our combo system to create a master sending object. Although not part of the base class, each send protocol class and the combo class created by IRLibCombo.h contain a single method send(…) which will send the appropriate signal based on the data and other parameters that you specify. That combo file is described in the next section.
1.3.3. The Combo Sending Class
In IRLib1 there was an omnibus sending class called IRsend which combined the 7 supported protocols into a single sender. However if you only used a small number of protocols it was wasting a lot of code space in your application. As the number of protocols we will support keeps increasing, this wasted space could be significant. We instead created a modular system in which you include the base sender class followed by header files for only the protocols that you want to use. This can save valuable space in your program. We highly recommend that you use this system rather than including IRLib2.h or IRLibAll.h unless you really need to include absolutely everything.
First we will describe how to use the system for a single protocol. Suppose you're only sending Sony codes. At the top of your file you would include…
#include "IRLibSendBase.h" | //Include the base class

#include "IRLib_P02_Sony.h" | //Include the protocol you want

IRsendSony mySender; | //Create an instance of the object
Note that the name of the class is IRsendSony. If you are using some of the protocol it would have that protocol name such as IRsendNEC, IRsendRC5 etc. If your application also would decode only Sony codes then you would include the IRLibDecodeBase.h prior to the protocol as well. Then to send a code you would do…
mySender.send(0xa8bca, 20);//Sony DVD power A8BCA, 20 bits

This passes the proper data and the fact that is a 20 bit version of the Sony protocol. If you are using multiple protocols your code might look like this…
#include <IRLibSendBase.h> | // First include the sendbase

#include <IRLib_P01_NEC.h> | // Now only the protocols you wish

#include <IRLib_P02_Sony.h> // to actually use. The lowest numbered #include <IRLib_P07_NECx.h> // must be first.

#include <IRLib_P09_GICable.h>

#include <IRLib_P11_RCMM.h>

#include <IRLibCombo.h> | // Combine them into "IRsend"

IRsend mySender; | // Create an instance
We begin by including header IRLibSendBase.h followed by the header files for each of the protocols you wish to use. NOTE: The lowest numbered protocol you're using must be the first included. Subsequent protocol includes need not be in numerical order but we recommend that you keep them in order anyway. If you would later decide to remove the top protocol then everything else would still be all right. When we say "lowest numbered" we do not mean that you have to use IRLib_P01_NEC.h in every sketch. We mean that among the protocols you are using, the lowest numbered one in your list must be first.
Note: If your application both sends and receives then you would also include the decoding base class prior to including all of the protocol classes.
After you have included the base file and all of your protocol files you then include the file IRLibCombo.h. It defines a new derived class called IRsend which combines all of your selected protocols into a single class. You should then create an instance of that class.
The IRsend has only one method that is implemented in IRLibCombo.h with the prototype as follows…
void IRsend::send(uint8_t type, uint32_t data, uint16_t data2,
uint8_t khz=38);
You will always invoke this method with at least the first three parameters. The first is always the protocol type. The legal values are found in the file IRLibProtocols/IRLibProtocols.h as follows…
#define UNKNOWN 0

#define NEC 1

#define SONY 2

#define RC5 3

#define RC6 4

#define PANASONIC_OLD 5

#define JVC 6

#define NECX 7

#define SAMSUNG36 8

#define GICABLE 9

#define DIRECTV 10

#define RCMM 11

//#define ADDITIONAL_12 12 //add additional protocols here

//#define ADDITIONAL_13 13
#define LAST_PROTOCOL 11 //Be sure to update this

The second parameter is the 32-bit data value that you will transmit. The third parameter "data2" can have a variety of uses. Most of the time it denotes the number of bits. For example the following line will send a power on signal for a Sony VCR/DVD player that uses a 20 bit Sony code.
mySender.send(SONY,0xa8bca, 20);//Sony DVD power A8BCA, 20 bits
Note that in this example, unlike our single protocol example, we had to specify which protocol we were using in the first parameter.
Many protocols have a fixed bit length so you can simply pass zero because whatever you pass is ignored. This third parameter can also be used as a repeat flag for some protocols. The optional fourth parameter is the frequency modulation. If this parameter is omitted or if it is present but equal to zero it will default to 38 kHz which is the most common frequency. Protocol UNKNOWN 0 is used for the IRsendRaw class. There is no IRsendHash class because there is no way to re-create the data stream from the hash code created by the IRdecodeHash decoder class.
See the example programs IRLib2/examples/rawRecv and IRLib2/examples/rawSend for example how to use this class. The prototype is…
void IRsendRaw::send(uint16_t *buf, uint8_t len, uint8_t khz);
The first parameter points to the array of values. You also need to specify the number of intervals. The third parameter is the modulation frequency to use. If you do not know the modulation frequency then we recommend that you use 38 for this value. The receiver and decoder classes cannot normally detect the modulation frequency. See the section on the IRfrequency class to see how to detect modulation frequency. For more information see the section on implementing your own protocols.
Complete details on how each protocol uses the combined sending object parameters can be found in section 1.4 Protocol Details.
1.4 Protocol Details
In this section will provide more details about each of the protocols supported by the library. Of special interest will be information regarding how the IRsend::send() method makes use of its various parameters differently in some protocols than others. The IRdecode::decode() is used consistently among all the protocols however there are some specific issues related to decoding that we will discuss for each protocol below.
The code for each protocol is in a header file which can be found in the IRLibProtocols folder. The file names are of the form IRLib_Pnn_Name.h where "nn" is the protocol number and "name" is the name of the protocol for example the Sony protocol is in IRLib_P02_Sony.h. There is no associated ".cpp" file for the protocols. All of the code is in the header file. This means that the code will be recompiled every time you compile your sketch. While this will slow down compilation slightly, the flexibility it gives us is well worth it. These files contain both the decoding and sending classes but a series of conditional compile flags insurers that if you do not include the base decoding class that the individual protocol decoding classes will not compile. Similarly if you do not include the sending base class, the individual protocol sending classes will not compile. If your application both sends and receives you must include both base classes before including the protocol classes.
The data sent in an IR signal is logically divided into subfields sometimes known as device numbers, sub device, function, subfunction, OEM codes, checksum fields and so on. IRLib ignores these distinctions and simply lumps all the data into one string of binary bits. Some reference material you will find lists as separate protocols any system that interprets that binary data differently. For example NEC protocol is a 32-bit sequence with a particular set of timing. That exact same timing and 32 bits of data is also used by protocols known as Apple and TiVo however they interpret those 32 bits differently than NEC. Because we do not care about the interpretation of the data, we do not treat these as separate protocols. We consider them all to be NEC protocols because for purposes of decoding and sending they are identical. Similarly some protocols make the use of a checksum or repeated sequences for error correction. For example Panasonic_Old is a 22 bit protocol in the first 11 bits contain data and the following 11 bits are the same data in binary ones compliment. We do not ensure that this rule is maintained in either encoding or decoding. Also note that in the samples in the following sections when we demonstrate how to send data, those data sequences are just random patterns we made up for illustration purposes. They are not necessarily valid sequences for those protocols and will not follow the internal rules for those protocols.
Additionally some protocols have different variations that use different numbers of bits and some have protocols which are identical except for the modulation frequency. We tried to create single decode and send routines that will handle as many of these variations at once. That way we do not have duplicate routines that waste a lot of valuable code space. So while some references may consider these variations different protocols, we try to lump together as much as we can to make the code as space efficient as possible.
After including the base class files followed by the protocol files then you include IRLibCombo.h which will combine them together to create the IRdecode and IRsend classes using all and only the protocols which you have selected. The following sections are organized in protocol number order.
Among the things we will discuss are the handling of repeat codes. Some protocols give you information to let you know whether or not a particular button was pressed individually or rather it was held down causing it to auto repeat. Some protocols use a special sequence called a "ditto" that does not contain the data that is being repeated. It presumes you have
remembered what was recently sent. It sends you a special signal that should be interpreted as "We held down the button and you should repeat what we just sent you". IRLib does not do this for you. It will send you a value equal to REPEAT_CODE which is defined in IRLibProtocols.h as 0xffffffff. Similarly if you send REPEAT_CODE it will generate that ditto sequence for you. Some other protocols make use of toggle bits. This is a particular bit that will toggle off and on if you repeatedly press and release the same button but will remain constant if you hold down the button and the signal repeats. Unlike a ditto, the data that is being repeated is available in the signal therefore you do not need to remember it from a previous transmission. IRLib does not manage toggle bits for you. It simply decodes what it receives and it's up to you to decide what to do if anything if that bit switches between successive receptions. Similarly it is up to you to decide whether or not to change the toggle bit when you are sending successive receptions. If you do not care whether a signal was the result of a series of individual
keypresses or was the result of a single held keypress then you may want to mask out the toggle bits for these protocols and ignore them.
At the end of each of these protocol sections we will give you a more detailed description of the timing of that protocol in what is known as IRP notation. This is a type of shorthand for describing infrared signals. See Appendix B for an explanation of this notation and a link to some reference material which gives the IRP notation for these protocols and many others that we have not yet supported.
1.4.1 NEC, Apple, TiVo and Pioneer Protocols
The NEC protocol is one of the most common and is used by a variety of manufacturers beyond NEC itself. There are 2 varieties known as NEC1 and NEC2. The only difference is the way in which they handle repeat codes. NEC1 makes use of a special ditto sequence which we will decode as the value REPEAT_CODE as described in the introduction to this section. The NEC2 protocol does not use dittos and does not make any distinction between repeated signals or individual keypresses.
Note that the timing of the ditto sequence for NEC1 is nearly identical to the ditto used by the GICable protocol. IRLib generally cannot distinguish between the two. The header timing for GICable consisting of a mark and a space is 8820,1960 and for NEC1 is 9024,2256. If you are using both protocols and you receive an NEC ditto immediately after receiving a GICable then you should presume it is a GICable and vice versa.
This protocol always is 32 bits long. Additional protocols known as Apple and TiVo also use the exact same timing pattern and 32 bits of data as NEC2 however they interpret those 32 bits differently. We however treat all of these as NEC. Additionally Pioneer protocol is identical to NEC2 except that it uses 40 kHz rather than 38 kHz modulation. Unless you are also using a TSMP58000 receiver along with your TSOPxxxx receiver and measuring the frequency as well as the timing pattern, you will not be able to distinguish between NEC2 and Pioneer. Note also that Pioneer sometimes requires a double sequence of data consisting of two different values in order to perform one function.
The code for this protocol is in IRLibProtocols/IRLib_P01_NEC.h. The prototype for the send class for this protocol is…
void IRsendNEC::send(uint32_t data, uint8_t kHz=38);
The optional second parameter allows you to support Pioneer by changing the frequency to 40 instead of the default 38. Here are some examples if you create an instance of the NEC sending class by itself.
IRsendNEC mySender;
…
mySender.send(0x1234abcd); //send NEC protocol mySender.send(REPEAT_CODE); //send NEC ditto sequence mySender.send(0xab12c3ff, 40); //send Pioneer protocol

When using the IRsend multi-protocol class there are always three parameters. The third parameter called "data2" is the frequency number. You should send it to either zero or 38 for NEC set it to 40 for pioneer. Here are some examples.
IRsend mySender;
…
mySender.send(NEC,0x1234abcd,0); //send NEC protocol mySender.send(NEC,REPEAT_CODE,0); //send NEC ditto sequence mySender.send(NEC,0xab12c3ff, 40); //send Pioneer protocol
This protocol begins with a header consisting of a very long mark and space followed by 32 data bits and a single stop bit which is not encoded by the library. Zeros and ones are distinguished by varying the duration of the space while keeping a constant length for the marks as is typical with most protocols. Here is the IRP notation for all of the protocols supported in this module.
NEC1: {38k,564}<1,-1|1,-3>(16,-8,D:8,S:8,F:8,~F:8,1,^108,(16,-4,1,^108)*)
NEC2: {38k,564}<1,-1|1,-3>(16,-8,D:8,S:8,F:8,~F:8,1,^108)+
Apple: {38.0k,564}<1,-1|1,-3>(16,-8,D:8,S:8,C:1,F:7,I:8,1,^108m,(16,-4,1,^108m)*) {C=~(#F+#PairID)&1)} C=1 if the number of 1 bits in the fields F and I is even. I is the remote ID. Apple uses the same framing as NEC1, with D=238 in normal use, 224 while pairing. S=135
TiVo: {38.4k,564}<1,-1|1,-3>(16,-8,133:8,48:8,F:8,U:4,~F:4:4,1,-78,(16,-4,1,-173)*)
Pioneer: {40k,564}<1,-1|1,-3>(16,-8,D:8,S:8,F:8,~F:8,1,^108m)+

1.4.2 Sony Protocol
The Sony protocol is used almost exclusively by Sony and is unlikely to be used by other manufacturers. The different varieties of the protocol are distinguished only by number of bits. Legal varieties are 8, 12, 15 and 20 bits. The protocol uses 40 kHz modulation however most TSOP receivers tuned to 38 kHz can still receive the signal reasonably well.
The code for this protocol is in IRLibProtocols/IRLib_P01_Sony.h. The prototype for the send class is…
void IRsendSony::send(uint32_t data, uint8_t nbits);
When using the IRsend multi-protocol class there are always three parameters. The third parameter called "data2" is the number of bits. Here are some examples…
IRsendSony mySender;
…
mySender.send(0x12abc,20); //send 20 bits Sony protocol mySender.send(0x12ab, 15); //send 50 bits Sony protocol or alternatively…

IRsend mySender;
…
mySender.send(SONY,0x12abc,20); //send 20 bits Sony protocol mySender.send(SONY,0x12ab, 15); //send 15 bits Sony protocol
The Sony specification requires that every time you press a button, the same signal is sent three times. So when you are receiving Sony signals you can expect each button press to produce three identical signals in a row. Our sending routine automatically repeats the sequence three times so that you only need to call send one time and it will handle the repeats. The specification does not make any distinction between successive keypresses versus a held keypress.
The protocol begins with a header consisting of a long mark and space followed by the data bits. Unlike most protocols which varies the length of the space and keep the length of the mark constant, Sony keeps the space constant and varies the length of the mark. We were able to implement this using our genericSend method however the logic for the decode method did not lend itself to the genericDecode so we had to implement a special decoder. No other known protocols use this system. The IRP notation for these protocols are…
Sony 8:{40k,600}<1,-1|2,-1>(4,-1,F:8,^22200u)
Sony 12: {40k,600}<1,-1|2,-1>(4,-1,F:7,D:5,^45m)+
Sony 15: {40k,600}<1,-1|2,-1>(4,-1,F:7,D:8,^45m)+
Sony 20: {40k,600}<1,-1|2,-1>(4,-1,F:7,D:5,S:8,^45m)+

1.4.3 Philips RC5, RC5-7F, and RC5-7F-57
The RC5 protocol was invented by Phillips but is very common and used by a variety of manufacturers. We support three of the four varieties of this protocol. The most common variety is designated simply as RC5 is a 13 bit protocol. There is also a 14 bit version known as RC5-7F. Both of these use a modulation frequency of 36 kHz however they can typically be received by standard 38 kHz TSOP receivers. There is another variation of RC5-7F known as RC5-7F-57 which is distinguished from RC5-7F only by the modulation frequency which is 57 kHz. It may be less likely that a 36 kHz receiver can accurately detect 57 kHz but it may be possible.
There is another variety known as RC5x which we do not currently support. It is so significantly different the other varieties that it will probably require a completely separate module.
The code for this protocol is in IRLibProtocols/IRLib_P03_RC5.h. The prototype for the send class for this protocol is…
void IRsendRC5::send(uint32_t data, uint8_t nBits=13,
uint8_t kHz=36);

The second and third parameters are optional and will default to 13 bits and 36 kHz which is the generic RC5 variety. Here are some examples if you create an instance of the RC5 sending class by itself.
IRsendRC5 mySender;
…
mySender.send(0x12ab); //send RC5 protocol default 13 bits 36 kHz mySender.send(0x3abc,14); //send RC5-7F 14 bits default 36 kHz mySender.send(0x3abc,14,57); //send RC5-7F-57 specify both
//bits and the kHz
When using the IRsend multi-protocol class there are always at least three parameters. The third parameter called "data2" is the number of bits and must always be specified as 13 or
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

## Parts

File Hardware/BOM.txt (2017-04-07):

Qty Value     Device                     Package          Parts    Description                          
2             DCBARRELPTH                DCJACK_2MM_PTH   CN1, CN2 2.0mm DC Barrel Jack                 
1             MA05-1                     MA05-1           SERIAL   PIN HEADER                           
1             AO3406		         SOT23-W          Q1       N-Channel Mosfet                     
1             XTAL/S                     QS               XT1      CRYSTAL                              
1   100k      R-EU_M0805                 M0805            R1       RESISTOR, European symbol            
2   100n      C-EUC0805                  C0805            C2, C3,  CAPACITOR, European symbol
							  C4, C6              
2   10k       R-EU_M0805                 M0805            R2, R3   RESISTOR, European symbol            
1   1M        R-EU_M0805                 M0805            R7       RESISTOR, European symbol            
1   1u        C-EUC0805                  C0805            C1       CAPACITOR, European symbol           
2   22p       C-EUC0805K                 C0805K           C7, C10  CAPACITOR, European symbol           
1   22u       CPOL-EUE2-4                E2-4             C8       POLARIZED CAPACITOR, European symbol 
1   78L05F    78L05F                     SOT89            IC2      POSITOIV-VOLTAGE REGULATORS          
1   ATMEGA328 ATMEGA168                  TQFP32-08        U2                                            
1   LDR       DIP-RES-LDR(2P-D2.3X3.7MM) PR-2.8-4.2X4.9MM R5       314120003                            
1   PNA460XM  PNA460XM                   PNA460XM         IR       IR 36KHz receiver

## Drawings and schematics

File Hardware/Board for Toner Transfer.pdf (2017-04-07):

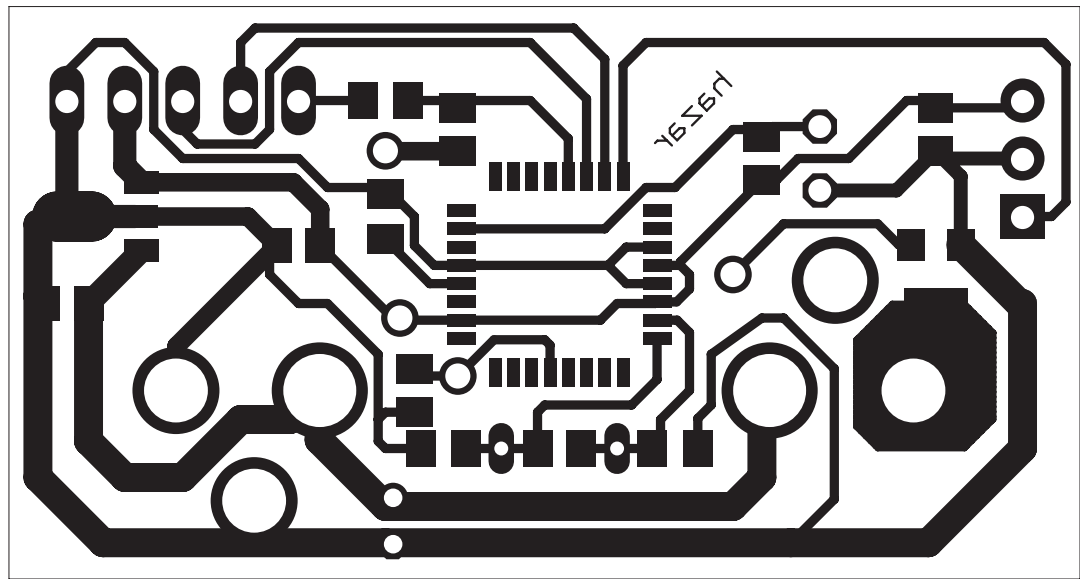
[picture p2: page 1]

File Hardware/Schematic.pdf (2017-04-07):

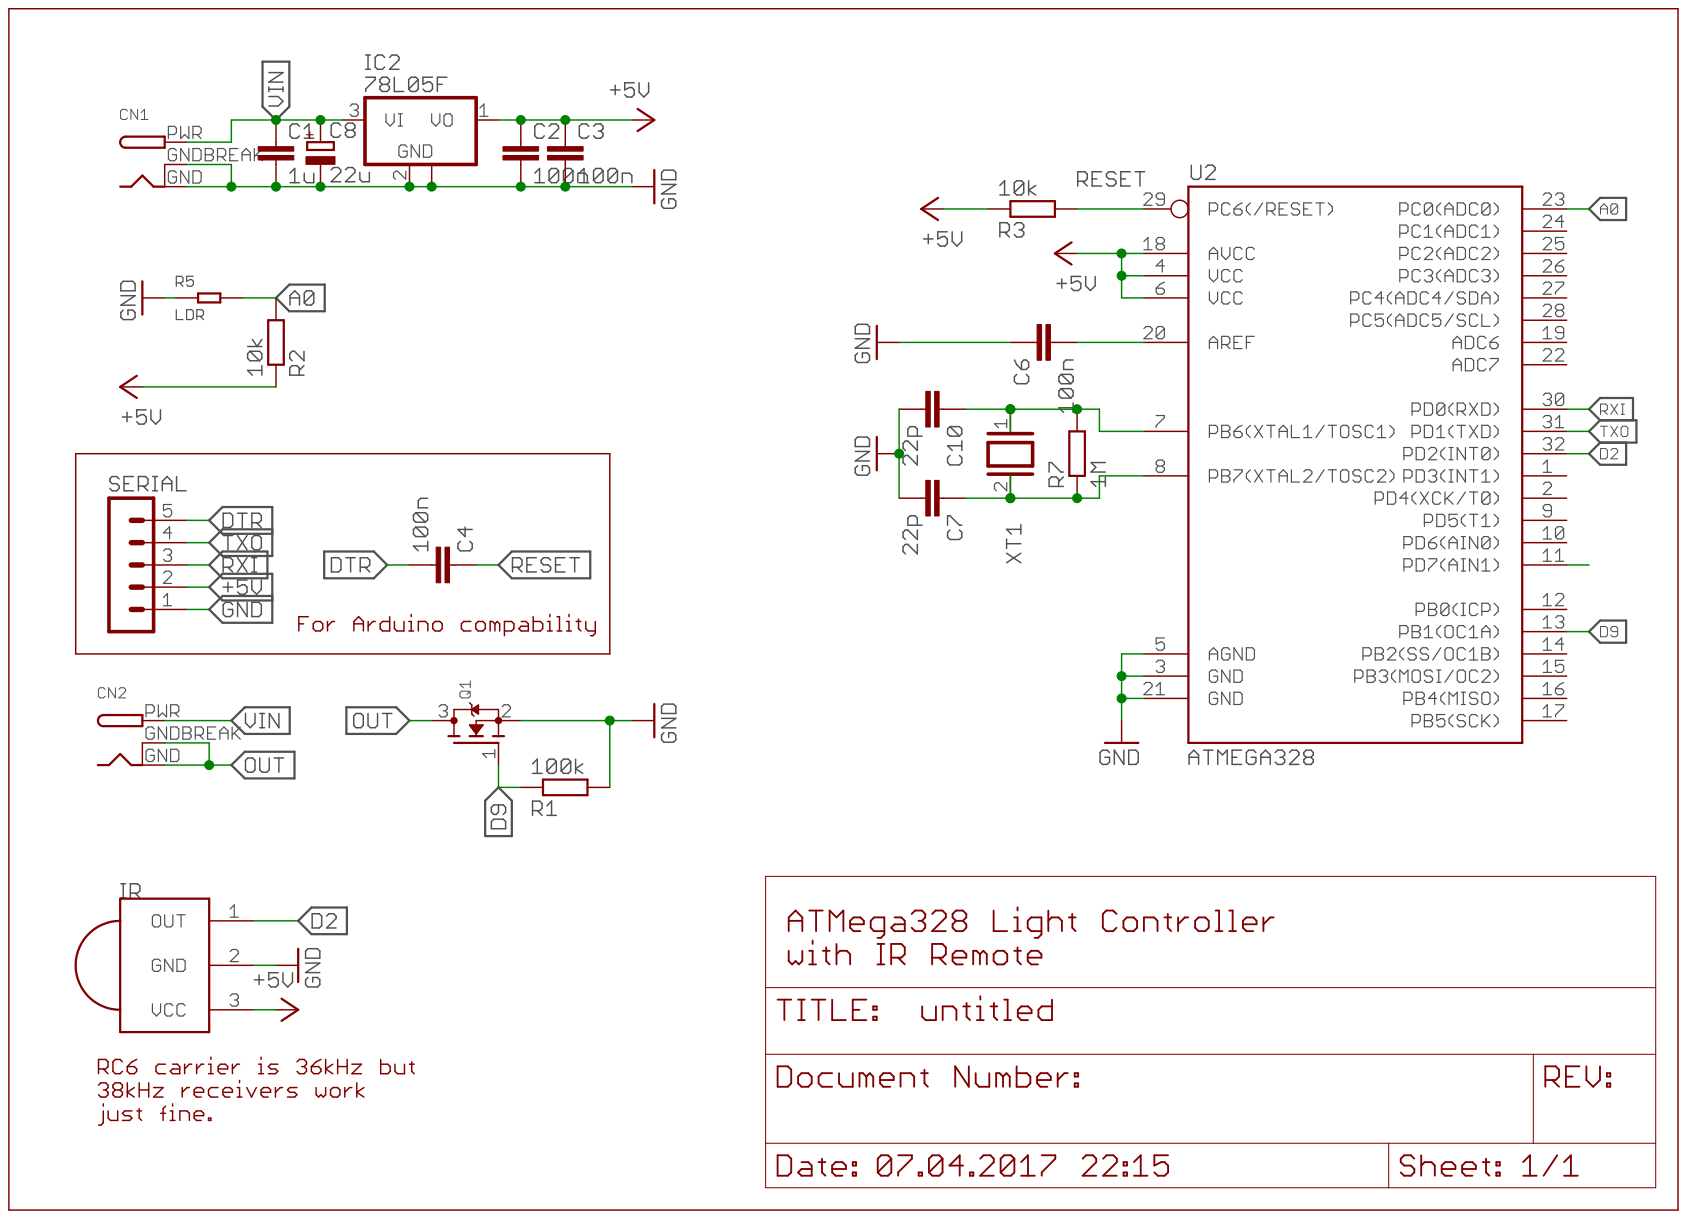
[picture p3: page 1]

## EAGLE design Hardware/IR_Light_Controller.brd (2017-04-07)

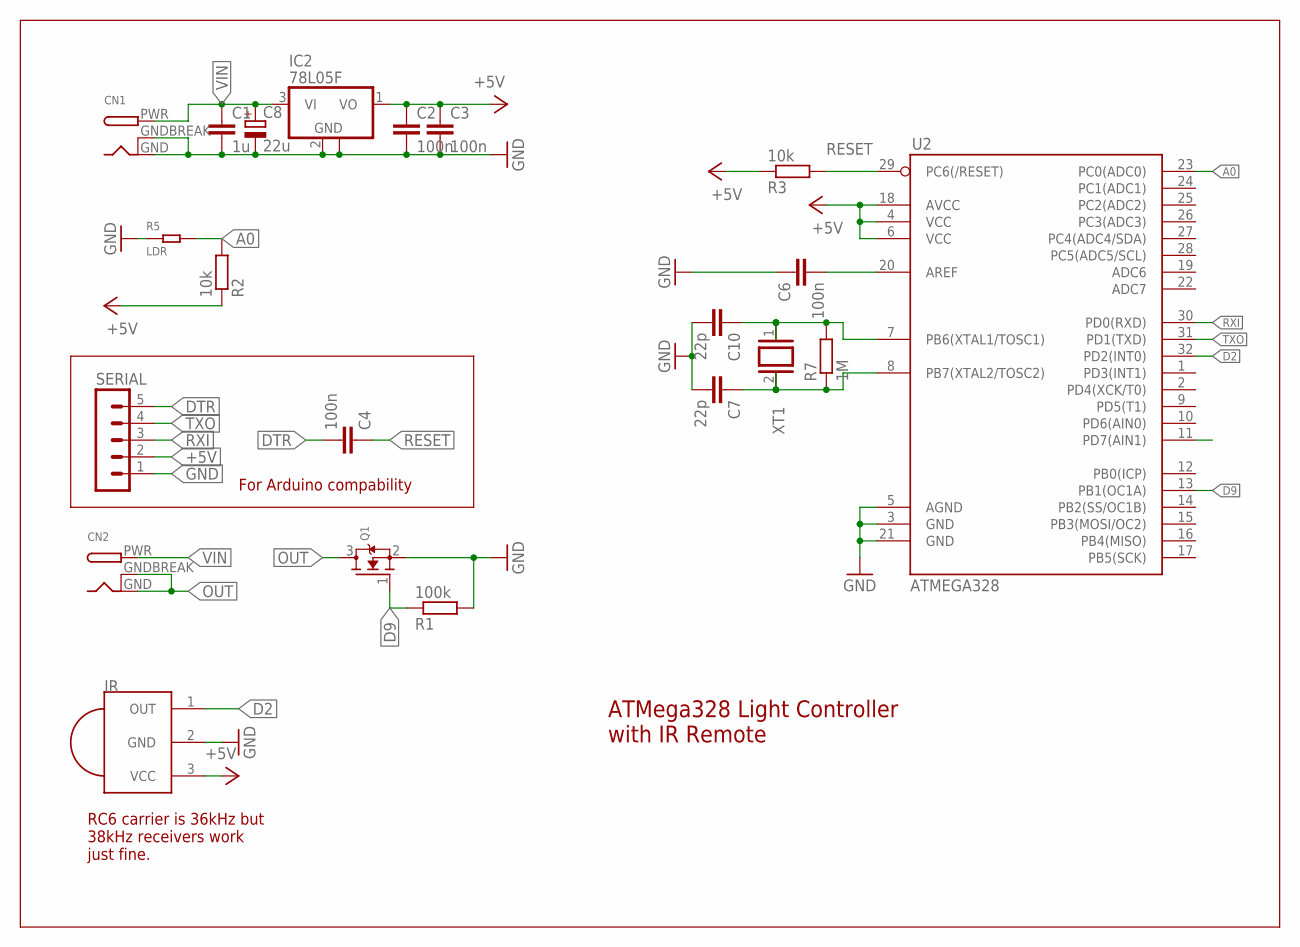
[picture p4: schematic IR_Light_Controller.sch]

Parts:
C1: 1u; C0805
C2, C3: 100n; C0805
C4, C6: 100n; C0805K
C7, C10: 22p; C0805K
C8: 22u; E2-4
CN1, CN2: DCBARRELPTH; DCJACK_2MM_PTH
IC2: 78L05F; SOT89
IR: PNA460XM
Q1: MOSFET-NWAVE; SOT23-W
R1: 100k; M0805
R2, R3: 10k; M0805
R5: LDR; PR-2.8-4.2X4.9MM
R7: 1M; M0805
SERIAL: MA05-1
U2: ATMEGA328; TQFP32-08
XT1: XTAL/S; QS

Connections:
+5V: C2.1, C3.1, IC2.1 (VO), IR.3 (VCC), R2.1, R3.1, SERIAL.2, U2.4 (VCC), U2.6 (VCC), U2.18 (AVCC)
A0: R2.2, R5.2, U2.23 (PC0(ADC0))
AREF: C6.2, U2.20 (AREF)
D2: IR.1 (OUT), U2.32 (PD2(INT0))
D7: U2.11 (PD7(AIN1))
D9: Q1.1 (G), R1.1, U2.13 (PB1(OC1A))
DTR: C4.2, SERIAL.5
GND: C1.2, C2.2, C3.2, C6.1, C7.2, C8.-, C10.2, CN1.GND, CN1.GNDBREAK, IC2.2 (GND), IC2.2@1 (GND), IR.2 (GND), Q1.2 (S), R1.2, R5.1, SERIAL.1, U2.3 (GND), U2.5 (AGND), U2.21 (GND)
OUT: CN2.GND, CN2.GNDBREAK, Q1.3 (D)
RESET: C4.1, R3.2, U2.29 (PC6(/RESET))
RXI: SERIAL.3, U2.30 (PD0(RXD))
TXO: SERIAL.4, U2.31 (PD1(TXD))
VIN: C1.1, C8.+, CN1.PWR, CN2.PWR, IC2.3 (VI)
XT1: C10.1, R7.2, U2.7 (PB6(XTAL1/TOSC1)), XT1.1
XT2: C7.1, R7.1, U2.8 (PB7(XTAL2/TOSC2)), XT1.2

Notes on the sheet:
RC6 carrier is 36kHz but 38kHz receivers work just fine.
ATMega328 Light Controller with IR Remote
For Arduino compability

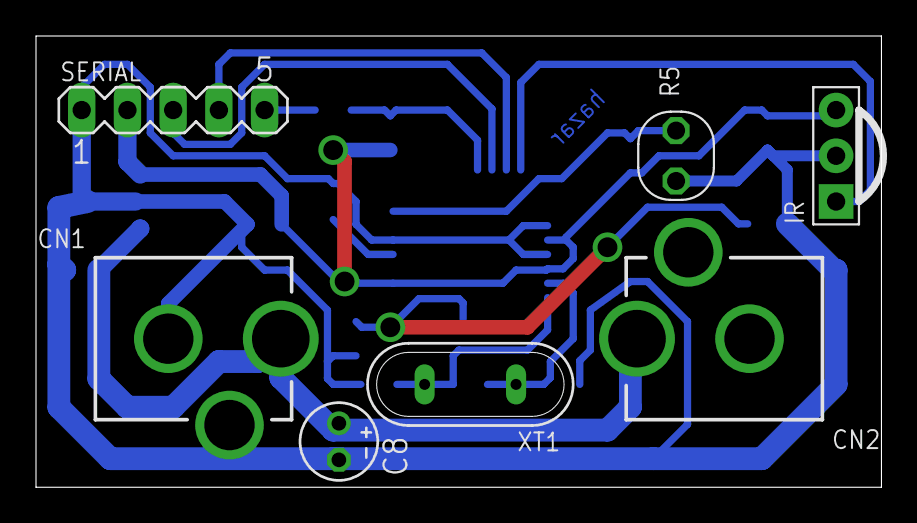
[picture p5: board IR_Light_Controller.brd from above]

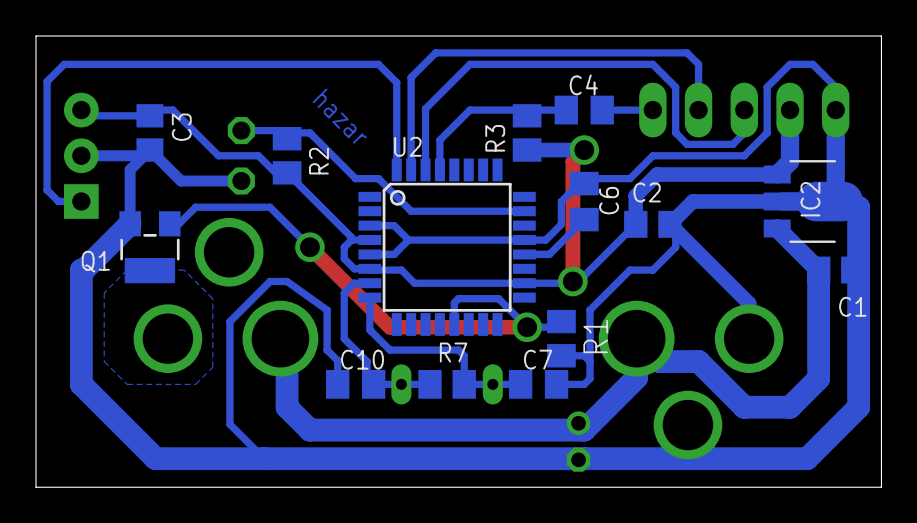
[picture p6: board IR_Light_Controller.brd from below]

Board: 2 copper layers, 47.0 x 25.1 mm, 21 parts (14 on the bottom side), 14 nets.

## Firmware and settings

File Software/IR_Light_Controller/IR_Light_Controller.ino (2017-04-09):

/*
  LED light strip controller using Media Center Remote (RC6 protocol)
  http://hazarkarabay.com.tr
*/

/* Defines */
#define TOP 0x0FFF // 12-bit resolution, 3906 Hz PWM

// Microsoft Media Center Remote teletext button codes
#define BUTTON_TOGGLE 0x800F045B // Red
#define BUTTON_BRI_DEC 0x800F045C // Green
#define BUTTON_BRI_INC 0x800F045D // Yellow
#define BUTTON_BREATHE 0x800F045E // Blue
// Buttons have two states, base address and +0x8000

#define BRI_STEP 5
#define CMD_TOGGLE_INTERVAL 200 // minimum time between light toggle
#define BRI_SET_INTERVAL 10 // fade in/out step time
#define LDR_THRESHOLD 900 // if LDR reading is greater than this, it is dark.

//#define DEBUG

/* Variables */
byte brightness = 0; // Current brightness, 0-100
byte targetBrightness = 0; // Wanted brightness, also 0-100. Used for fade effect while changing.
float luminance = 0; // 0-1
unsigned int pwmValue = 0; // 0-4096 (12-bit)
unsigned long lastCommand = 0;
unsigned long lastBrightnessChange = 0;
unsigned long lastLDRChange = 0;
unsigned int LDRValue = 0;
bool LDRStatus = false; // true=dark, false=lit

/* Includes */
#include "Functions.h"
#include <IRLibRecv.h>
#include <IRLibDecodeBase.h>
#include <IRLib_P04_RC6.h>
#include <IRLibCombo.h>

/* Library init */
IRrecv myReceiver(2);  // pin number for the IR receiver
IRdecode myDecoder;

void setup() {
  // Timer1 PWM Setup - Fixed on PB1, Arduino pin 9
  // Register init
  TCCR1A = 0;  // Timer/Counter1 Control Register A
  TCCR1B = 0;  // Timer/Counter1 Control Register B
  TIMSK1 = 0;   // Timer/Counter1 Interrupt Mask Register
  TIFR1 = 0;   // Timer/Counter1 Interrupt Flag Register
  ICR1 = TOP;
  OCR1A = 0; // On the contrary of popular belief, value of 0 *will* output some PWM.
  OCR1B = 0; //

  // Set clock prescale to 1 for maximum PWM frequency
  TCCR1B |= _BV(CS10);

  // Set to Timer/Counter1 to Waveform Generation Mode 14: Fast PWM with TOP set by ICR1
  TCCR1A |= _BV(WGM11);
  TCCR1B |= _BV(WGM13) | _BV(WGM12);

  // Set PB1 output
  pinMode(9, OUTPUT);

  myReceiver.enableIRIn(); // Start the receiver

#ifdef DEBUG
  Serial.begin(115200);
  Serial.println(F("Can you hear me?"));
#endif
}

void loop() {
  // IR receive and decode stuff
  if (myReceiver.getResults()) {
    if (myDecoder.decode()) {
      switch (myDecoder.value) {
        case BUTTON_TOGGLE:
        case BUTTON_TOGGLE+0x8000:
          // Throttle IR command processing
          if (millis() > lastCommand + CMD_TOGGLE_INTERVAL) {
            DEBUG_PRINT(F("TOGGLE"));
            targetBrightness = (targetBrightness) ? 0 : 100;
          }
          break;
        case BUTTON_BRI_DEC:
        case BUTTON_BRI_DEC+0x8000:
          DEBUG_PRINT(F("DEC"));
          if (targetBrightness > BRI_STEP)
            targetBrightness -= BRI_STEP;
          else targetBrightness = 0;
          break;
        case BUTTON_BRI_INC:
        case BUTTON_BRI_INC+0x8000:
          DEBUG_PRINT(F("INC"));
          if (targetBrightness + BRI_STEP > 100)
            targetBrightness = 100;
          else targetBrightness += BRI_STEP;
          break;
        case BUTTON_BREATHE:
        case BUTTON_BREATHE+0x8000:
          // TODO: Insert crazy light effect here.
          DEBUG_PRINT(F("*heavy breating*"));
          break;
      }
      lastCommand = millis();
    }
    
    myReceiver.disableIRIn();
    myReceiver.enableIRIn();
  }

  // Application logic
  LDRValue = analogRead(A0);

  if (LDRValue > LDR_THRESHOLD && !LDRStatus) {
    // Currently dark but previous status is lit
    lastLDRChange = millis();
    LDRStatus = true;

    DEBUG_PRINT2(F("LDR Status Changed: "), LDRStatus);
  } else if (LDRValue < LDR_THRESHOLD && LDRStatus) {
    // Currently lit but previous status is dark
    lastLDRChange = millis();
    LDRStatus = false;

    DEBUG_PRINT2(F("LDR Status Changed: "), LDRStatus);
  }

  // Making a decision at first power on immediately
  if (lastLDRChange == 0) {
    targetBrightness = (LDRStatus) ? 100 : 0;
    DEBUG_PRINT2(F("Power-on decision was made. Brightness set to "), targetBrightness);
    delay(1);
    lastLDRChange = millis();
  }


  // Fade in/out effect while changing brightness
  if (millis() - lastBrightnessChange > BRI_SET_INTERVAL) {
    lastBrightnessChange = millis();
    if (targetBrightness > brightness) {
      brightness++;
    } else if (targetBrightness < brightness) {
      brightness--;
    }

    setBrightness(brightness);
    //DEBUG_PRINT(brightness);
  }
}

/* Helper functions */

inline void setPWM(unsigned int val) {
  if (val == 0) {
    // Disconnecting timer to taking pin under our control.
    TCCR1A &= ~_BV(COM1A1);
    digitalWrite(2, LOW);
  } else {
    // If needed: Connect pin to timer
    if (OCR1A == 0)
      TCCR1A |= _BV(COM1A1);
  }
  OCR1A = constrain(val, 0, TOP);
}

inline unsigned int calculatePWM(byte bri) {
  bri = constrain(bri, 0, 100);

  // Perceived lightness for humans - using psychometric lightness formula, CIE 1931
  // http://photonstophotos.net/GeneralTopics/Exposure/Psychometric_Lightness_and_Gamma.htm
  if (bri > 8) {
    luminance =  pow(((bri + 16.0) / 116), 3);
  } else {
    luminance = (bri / 903.3);
  }

  return int(luminance * TOP); // Adjust to required resolution
}

inline void setBrightness(byte val) {
  setPWM(calculatePWM(val));
}

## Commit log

2017-04-07 BOM and Datasheets
2017-04-09 IR lockup workaround and reorganization for Arduino IDE
    Workaround for #1 and file reorganization required for Arduino IDE.
    [IR_Light_Controller.ino]
